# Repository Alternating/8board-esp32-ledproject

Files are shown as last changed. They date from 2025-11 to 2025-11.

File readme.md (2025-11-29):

# Modular LED Sign System - Multi-Board Display Controller

## 🎯 Project Overview

## Videos 
- https://youtu.be/qU0nfLclvcI - example of working with 8 boards
- https://youtube.com/shorts/jiU6isPC810?feature=share - battery holder and hanger combo

WiFi-controlled modular LED matrix sign system supporting:
- **Multiple display boards** (up to 8 boards)
- **Battery powered** - Portable operation with LiFePO4 batteries
- **Word sequencing** - Flash individual words in sequence
- **Scrolling text** - Smooth pixel-by-pixel scrolling
- **Individual characters** - Display single letters/numbers/symbols
- **Full effect control** - Blink, fade, color cycle with adjustable speeds
- **Web interface** - Mobile-friendly control panel
- **Brightness control** - 0-100 range for optimal viewing
- **3D printable mount** - Battery holder/hanger included

---
Example:

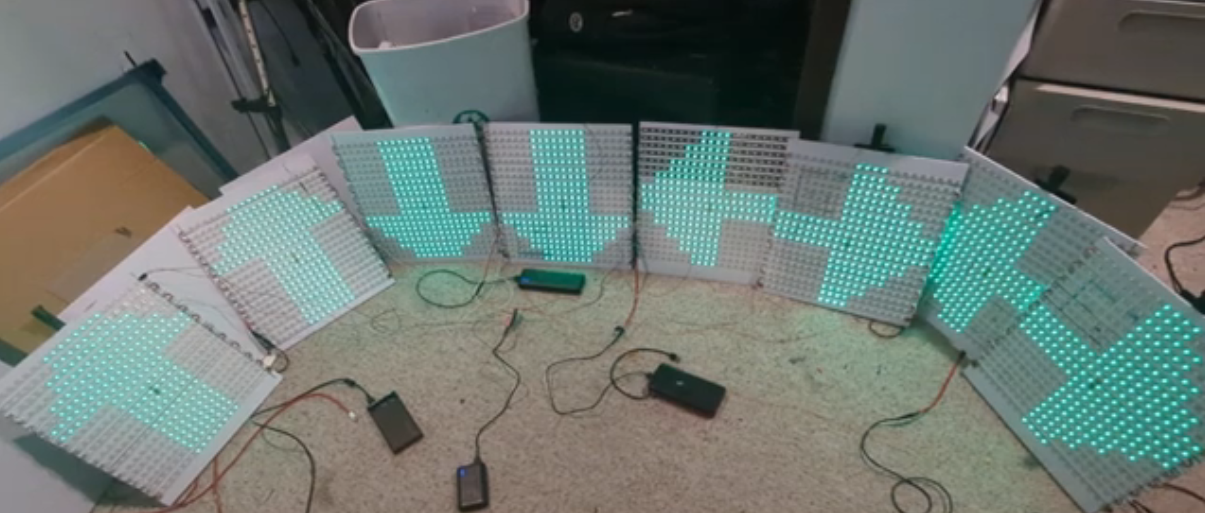
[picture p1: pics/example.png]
example WorkingExample


---
## 🛒 Parts List & Shopping Guide

### Complete Bill of Materials

All parts needed to build a complete battery-powered LED sign system. Links go directly to the exact products used in this build.

| Item | Description | Qty | Link |
|---|---|-----|---|
| **ESP32 Microcontroller** | ESP32 ESP-WROOM-32 Development Board<br>• 2.4GHz WiFi + Bluetooth<br>• Dual core processor<br>• USB Type-C interface<br>• 30 pin<br>• Compatible with Arduino IDE | 3-pack<br>(1 per sign) | [Amazon - ESP32 3-Pack](https://www.amazon.com/dp/B0DN61LVYV?ref_=ppx_hzsearch_conn_dt_b_fed_asin_title_12&th=1) |
| **LiFePO4 Battery** ⭐ | Rechargeable 6V 6Ah LiFePO4 Battery<br>• Built-in USB charging<br>• 2000+ cycle life<br>• Built-in BMS protection<br>• F1 terminals<br>• 0.7 lbs per battery | 2-pack<br>(1-2 per sign) | [Amazon - LiFePO4 2-Pack](https://www.amazon.com/dp/B0D6YJ1RK6?ref=ppx_yo2ov_dt_b_fed_asin_title&th=1) |
| **Buck Converter** | XL4015 DC-DC Step-Down Converter<br>• 5A output (4-38V input)<br>• 96% efficiency<br>• LED indicators<br>• Adjustable voltage | 10-pack<br>(1 per board) | [Amazon - XL4015 10-Pack](https://www.amazon.com/dp/B0D9JQBQYJ?ref=ppx_yo2ov_dt_b_fed_asin_title) |
| **LED Strip Lights** | WS2812B 5V Addressable LED Strip<br>• Individual pixel control<br>• 60 LEDs/meter (or 144/meter)<br>• 5V power<br>• 400 LEDs per 20×20 board | 6m roll<br>(per board)<br>Custom 10m available | [Amazon - WS2812B 6m](https://www.amazon.com/dp/B01CDTEJBG?ref_=ppx_hzsearch_conn_dt_b_fed_asin_title_2&th=1)<br>*Custom 10m direct from BTF* |
| **Power Connectors** | DC Power Pigtail Barrel Plug<br>• 2.1mm × 5.5mm<br>• Male + Female pairs<br>• **Real 18AWG** wire<br>• 12V 5A rated | 10 pairs | [Amazon - DC Pigtail 10-Pack](https://www.amazon.com/dp/B072BXB2Y8?ref=ppx_yo2ov_dt_b_fed_asin_title) |
| **Battery Connectors** | F1 Female Spade Lug Connector<br>• 0.187" (4.75mm)<br>• For LiFePO4 battery terminals<br>• Model: TCC-18N2 | As needed | [BatterySpec - F1 Connectors](https://www.batteryspec.com/cgi-bin/cart.cgi?action=link&product=1045) |
| **Hookup Wire** | 22 AWG Stranded Silicone Wire<br>• 6 colors (60ft each)<br>• Flexible silicone insulation<br>• Total: 360 feet<br>• Colors: Red, Black, Yellow, Blue, White, Green | 1 kit | [Amazon - 22AWG Wire Kit](https://www.amazon.com/dp/B0BWGXH5SF?ref_=ppx_hzsearch_conn_dt_b_fed_asin_title_2&th=1) |
| **Dupont Connectors** | Dupont Connector Kit<br>• 1550 pieces<br>• Headers, housings, pins<br>• Male/Female connectors<br>• For ESP32 connections | 1 kit | [Amazon - Dupont Kit](https://www.amazon.com/IWISS-1550PCS-Connector-Headers-Balancer/dp/B08X6C7PZM/) |
| **Mounting Board** | White Foam Board<br>• 20" × 30" sheets<br>• LED matrix backing<br>• Lightweight and rigid<br>• Available at local Walmart | 1 per board | [Walmart - Foam Board](https://www.walmart.com/ip/Pen-Gear-White-Foam-Board-20-x-30/5347546821) |

### Cost Breakdown

**Single Board Setup (Battery Powered):**

| Component | Cost | Notes |
|---|---|---|
| ESP32 (from 3-pack) | ~$8 | 3 boards for ~$24 |
| LiFePO4 Battery (from 2-pack) | ~$12 | 2 batteries for ~$24 |
| XL4015 Converter (from 10-pack) | ~$1.50 | 10 units for ~$15 |
| WS2812B LED Strip (6m) | ~$25 | Per board |
| Foam Board | ~$2 | Local pickup |
| Wires & Connectors | ~$5 | From kits above |
| **Total per board:** | **~$53.50** | Complete portable sign |

**Additional boards:** ~$45 each (battery, LEDs, converter, foam board)

**Shared Components (one-time purchase):**
- Wire kit: $13 (lasts many builds)
- Dupont kit: $15 (lasts many builds)
- DC connectors: $11 (10 pairs)
- F1 connectors: $5 (as needed)

### What You Get

**For ~$54 per board:**
- ✅ Fully portable LED sign (battery powered)
- ✅ 83 minutes runtime (166 min with 2 batteries)
- ✅ WiFi controlled via phone/computer
- ✅ USB rechargeable (use any phone charger)
- ✅ 20×20 LED matrix (400 individually controllable LEDs)
- ✅ Multiple display modes (scrolling, static, word sequence)
- ✅ Full RGB color control
- ✅ Built-in effects (blink, fade, color cycle)
- ✅ Professional 3D-printed battery mount (STL included)

### Optional Upgrades

| Item | Purpose | Approx. Cost |
|---|---|---|
| **Logic Level Shifter** | Convert 3.3V to 5V signals<br>Improves LED reliability | $5-8 |
| **LED Voltage Meter** | Monitor battery level<br>Shows real-time voltage | $8-12 |
| **On/Off Switch** | Power control<br>10A rated rocker switch | $3-5 |
| **Heatsinks** | Cooling for XL4015<br>If running hot | $3-5 |
| **Extra Batteries** | Extended runtime<br>Swap batteries for all-day use | $12 each |
| **USB Fast Charger** | Faster battery charging<br>2-3A output recommended | $8-15 |

### Quantity Guide

**Building 1 Sign:**
- 1× ESP32 (buy 3-pack, keep spares)
- 1× Battery (buy 2-pack, extend runtime or keep spare)
- 1× XL4015 (buy 10-pack, massive spares)
- 1× LED strip (6m minimum)
- 1× Foam board
- Wire/connectors from kits

**Building 2 Signs:**
- 2× ESP32 (from 3-pack)
- 2× Batteries (use full 2-pack)
- 2× XL4015 (from 10-pack)
- 2× LED strips
- 2× Foam boards
- Wire/connectors from kits

**Building 4 Signs:**
- 2× ESP32 3-packs (6 total, 2 spare)
- 2× Battery 2-packs (4 total)
- 1× XL4015 10-pack (6 spare)
- 4× LED strips
- 4× Foam boards
- Wire/connectors from kits

### Where to Buy Alternatives

**If Amazon links don't work or out of stock:**

**ESP32:**
- AliExpress: Search "ESP32 WROOM development board"
- eBay: Often cheaper but slower shipping
- Local electronics stores: Higher price but immediate

**LiFePO4 Batteries:**
- Search: "6V 6Ah LiFePO4 USB charging BMS"
- Alternative brands: Ampere Time, ExpertPower, Renogy
- **Must have:** Built-in BMS + USB charging

**XL4015 Buck Converters:**
- eBay: Often $8-10 for 5-pack
- AliExpress: Cheapest but slow shipping (4-6 weeks)
- Search: "XL4015 5A buck converter adjustable"

**WS2812B LED Strips:**
- BTF-Lighting Store (direct): Best quality, custom lengths
- AliExpress: Cheaper, verify 5V and 60 LED/m
- eBay: Quick shipping options
- **Important:** Get 5V version, not 12V!

**Wire & Connectors:**
- Local electronics stores (RadioShack alternatives)
- Hardware stores for basic wire
- Online: Adafruit, SparkFun (higher quality)

### Important Specifications

**When Buying LED Strips:**
- ✅ **Must be 5V** (not 12V or 24V)
- ✅ WS2812B chipset (not WS2811 or SK6812)
- ✅ 60 LEDs/meter minimum (144/meter is better but pricier)
- ✅ White PCB preferred (better light diffusion on foam)
- ✅ IP30 (non-waterproof) is fine for indoor use

**When Buying Batteries:**
- ✅ 6V nominal voltage (5.5-6.4V range)
- ✅ 6Ah capacity minimum (5Ah okay, 7-10Ah better runtime)
- ✅ **Must have built-in BMS** (critical for safety)
- ✅ USB charging port (makes life easier)
- ✅ F1 terminals (0.187" blade terminals)
- ✅ LiFePO4 chemistry (safer than Li-ion)

**When Buying Buck Converters:**
- ✅ XL4015 chipset (not LM2596 - less efficient)
- ✅ 5A minimum output current
- ✅ 4-38V input range (must handle 6V battery)
- ✅ Adjustable output (1.25-36V)
- ✅ LED indicators preferred

### Tips for Buying

💡 **Money Saving Tips:**
1. Buy in bulk (3-packs, 10-packs) - cheaper per unit
2. Check eBay for converters - often half Amazon price
3. Get foam board locally (avoids shipping cost)
4. One wire kit lasts 5+ builds
5. Extra ESP32s make good spares or other projects

⚠️ **What NOT to Compromise On:**
1. **Battery quality** - Must have BMS, buy from reputable seller
2. **LED strip** - Cheap strips fail, stick to WS2812B
3. **Wire gauge** - Don't go thinner than 22 AWG for data, 18 AWG for power
4. **ESP32 authenticity** - Clones often have WiFi issues

🎯 **Best Value Strategy:**
- Order all at once (save on shipping)
- Get 2-packs/3-packs even for 1 sign (spares are invaluable)
- Check eBay before Amazon (often 20-30% cheaper)
- Wait for sales (Prime Day, Black Friday)
- Bundle items from same seller (combined shipping)

---

## 📌 ESP32 GPIO Pin Configuration

### Pin Mapping Reference

The following table maps GPIO numbers to the **actual board labels** on the ESP-WROOM-32:

| Board # | GPIO Pin | Board Label | Wire Color (Suggested) | Notes |
|---|---|---|---|---|
| Board 1 | GPIO 5 | **CS** | Red | Default/Primary board |
| Board 2 | GPIO 16  | **RX2** | Orange | UART2 RX |
| Board 3 | GPIO 17  | **TX2** | Yellow | UART2 TX |
| Board 4 | GPIO 18  | **SCK** | Green | SPI Clock |
| Board 5 | GPIO 19  | **MISO** | Blue | SPI MISO |
| Board 6 | GPIO 21  | **SDA** | Purple | I2C Data |
| Board 7 | GPIO 22  | **SCL** | Gray | I2C Clock |
| Board 8 | GPIO 23  | **MOSI** | White | SPI MOSI |

### Pin Location Quick Reference

**Right Side of Board (looking at USB port at bottom):**
- Pin 15: GPIO 23 (MOSI) - Board 8
- Pin 14: GPIO 22 (SCL) - Board 7
- Pin 13: GPIO 1 (TX0) - Not used
- Pin 12: GPIO 3 (RX0) - Not used
- Pin 11: GPIO 21 (SDA) - Board 6
- Pin 10: GPIO 19 (MISO) - Board 5
- Pin 9: GPIO 18 (SCK) - Board 4
- Pin 8: GPIO 5 (CS) - Board 1
- Pin 7: GPIO 17 (TX2) - Board 3
- Pin 6: GPIO 16 (RX2) - Board 2

### Important Notes

⚠️ **Do NOT use these pins** (reserved for ESP32 system):
- GPIO 0, 2, 15 (boot mode pins)
- GPIO 6-11 (connected to flash memory)
- GPIO 1, 3 (UART0 TX/RX - USB serial)

✅ **Safe to use** - All 8 pins listed above are safe for LED data output

---

## 🔌 Hardware Setup

### Required Components

**Core Components:**
- **ESP-WROOM-32** development board
- **WS2812B LED matrices** (20×20 pixels each)
- **470Ω resistors** (one per board) - between ESP32 pin and LED data input
- **Wire** (16-18 AWG recommended)

**Power Options (choose one):**

**Option A: Wall Power (Permanent Installations)**
- **5V power supply** (adequate for number of boards)
  - Estimate: 60mA per LED at full brightness (400 LEDs × 60mA = 24A max)
  - Typical usage at 25% brightness: ~5A per board
  - 1 board: 10A 5V power supply
  - 2 boards: 20A 5V power supply
  - 4+ boards: Multiple power supplies
- **1000µF capacitor** (across power supply terminals)

**Option B: Battery Power (Portable) ⭐ Recommended for portability**
- **LiFePO4 6V 6Ah batteries** (1 per board for 83 min runtime)
  - Built-in BMS protection
  - USB charging (use any phone charger)
  - Weight: Only 0.7 lbs per battery
  - Cost: ~$12-15 each
- **XL4015 DC-DC buck converters** (1 per board)
  - Converts 6V battery to 5V for LEDs
  - 96% efficient
  - Cost: ~$10-12 for 3-pack
- **3D printable battery mount** (STL file included)

**Optional but Recommended:**
- **Logic level shifter** - Converts 3.3V ESP32 signals to 5V for WS2812B
- **On/off switch** - For battery configurations
- **Voltage meter** - Monitor battery level

### Wiring Each Board

**Wall Power Configuration:**
```
ESP32 GPIO Pin → 470Ω Resistor → LED Matrix Data In
                                  
Power Supply 5V+ → LED Matrix VCC
Power Supply GND → LED Matrix GND
                 → ESP32 GND (IMPORTANT!)
```

**Battery Power Configuration:**
```
ESP32 GPIO Pin → 470Ω Resistor → LED Matrix Data In

Battery 6V+ → XL4015 IN+
Battery GND → XL4015 IN- → ESP32 GND (IMPORTANT!)

XL4015 OUT+ (5.0V) → LED Matrix VCC  
XL4015 OUT- → LED Matrix GND → ESP32 GND (common ground!)
```

**Critical:** All grounds must be connected together:
- Battery ground (-)
- XL4015 OUT-
- ESP32 GND
- LED board GND

**See "Battery Power" section for complete battery wiring diagrams**

### Multi-Board Chain Configuration

**Option 1: Individual Control** (Recommended)
- Each board has its own GPIO pin
- Better control and troubleshooting
- Can display different content on each board

```
ESP32 GPIO 5  → Board 1 Data In
ESP32 GPIO 16 → Board 2 Data In
ESP32 GPIO 17 → Board 3 Data In
... etc
```

**Option 2: Daisy Chain** (Current code uses this)
- All boards connected in series on one GPIO
- Simpler wiring but limited to sequential display

```
ESP32 GPIO 5 → Board 1 Data In
Board 1 Data Out → Board 2 Data In
Board 2 Data Out → Board 3 Data In
... etc
```

---

## 🔋 Battery Power (Portable Operation)

### Battery Power Overview

Make your LED sign portable with rechargeable LiFePO4 batteries! These batteries provide:
- ✅ **USB charging** - Use any phone charger
- ✅ **Long runtime** - 83+ minutes per board
- ✅ **Lightweight** - Only 0.7 lbs per battery
- ✅ **Safe** - Built-in BMS protection
- ✅ **Long life** - 2000+ charge cycles
- ✅ **3D printable mount** - Battery holder/hanger STL included

### Recommended Battery: LiFePO4 6V 6Ah

**Specifications:**
- **Voltage:** 6V (5.5-6.4V operating range)
- **Capacity:** 6Ah (36Wh energy)
- **Chemistry:** LiFePO4 (Lithium Iron Phosphate)
- **Weight:** 0.7 lbs (compared to 2.2 lbs for lead acid)
- **BMS:** Built-in protection (overcharge, over-discharge, overcurrent)
- **Charging:** USB input (use any USB adapter)
- **Terminals:** F1 blade terminals (0.187")
- **Cycle Life:** 2000+ charge/discharge cycles
- **Safety:** Won't catch fire, very stable chemistry

**Where to buy:**
- Amazon: Search "6V 6Ah LiFePO4 battery USB"
- Typical price: $12-15 each (often sold in 2-packs for $24)
- Example: TOPUSSE 6V 6Ah LiFePO4 (2-pack)

### Voltage Converter: XL4015 Buck Converter

**Required to convert 6V battery to 5V for LEDs:**

**Specifications:**
- **Model:** XL4015 DC-DC Step-Down Buck Converter
- **Input:** 4-38V DC (works perfectly with 6V battery)
- **Output:** 1.25-36V adjustable (set to 5.0V)
- **Current:** 5A maximum (4.5A recommended)
- **Efficiency:** 96% (excellent!)
- **Power:** 75W max
- **Size:** 54×23×18mm
- **Price:** $10-12 for 3-pack

**Where to buy:**
- Amazon: Search "XL4015 DC-DC buck converter"
- Get the 3-pack (use 1 per board, keep spares)

### Runtime Calculations

**Power consumption at 25% brightness (typical use):**
- 1 board: 5A @ 5V = 25W
- 2 boards: 10A @ 5V = 50W
- 3 boards: 15A @ 5V = 75W
- 4 boards: 20A @ 5V = 100W

**Single 6V 6Ah battery (36Wh energy):**

| Boards | Runtime | Notes |
|---|---|---|
| 1 | **83 minutes** | Great for demos/events |
| 2 | **41 minutes** | Good for short displays |
| 3 | **28 minutes** | Quick presentations |
| 4 | **21 minutes** | Brief shows |

**Two batteries in parallel (72Wh total):**

| Boards | Runtime | Notes |
|---|---|---|
| 1 | **166 minutes** (2.8 hrs) | All-day events |
| 2 | **83 minutes** (1.4 hrs) | Extended displays |
| 3 | **55 minutes** | Longer shows |
| 4 | **41 minutes** | Good presentations |

### Battery Power Wiring

#### Single Board Configuration:

```
┌─────────────────────┐
│  LiFePO4 Battery    │
│  6V 6Ah w/ BMS      │
│                     │
│  [+] Terminal       │
│   │                 │
│   └─────────────┐   │
│                 │   │
│  [-] Terminal   │   │
│   │             │   │
└───┼─────────────┘   │
    │                 │
    │  ┌───────────┐  │
    └──┤ XL4015    │  │
       │ IN-       │  │
    ┌──┤ IN+       │  │
    │  │           │  │
    │  │ OUT+ ─────┼──┼──→ LED Board VCC
    │  │    (5.0V) │  │
    │  │ OUT- ─────┼──┼──→ LED Board GND
    │  └───────────┘  │         ↓
    │                 │    ESP32 GND
    └─────────────────┴──→ (common ground!)

Components:
• 1× LiFePO4 6V 6Ah battery ($12-15)
• 1× XL4015 buck converter ($4 from 3-pack)
• 16-18 AWG wire
• F1 blade connectors

Runtime: 83 minutes @ 1 board
Weight: 0.7 lbs total
```

#### Two Boards with Separate Converters:

```
┌──────────────┐
│  LiFePO4     │
│  6V 6Ah      │
│              │
│  [+] ────┬───┼─────────┐
│          │   │         │
│  [-] ──┐ │   │         │
│        │ │   │         │
└────────┼─┘   │         │
         │     │         │
    ┌────┴──┐ ┌┴──────┐  │
    │XL4015 │ │XL4015 │  │
    │  #1   │ │  #2   │  │
    │       │ │       │  │
    │OUT+───┼─┼───→ Board 1 VCC
    │       │ │       │
    │OUT-─┐ │ │OUT+───┼──→ Board 2 VCC
    │     │ │ │       │
    └─────┘ │ │OUT-─┐ │
            │ │     │ │
            └─┴─────┴─┴──→ All GND common

Runtime: 41 minutes @ 2 boards
Weight: 0.7 lbs
```

#### Extended Runtime: Two Batteries in Parallel

```
┌─────────┐  ┌─────────┐
│Battery 1│  │Battery 2│
│ 6V 6Ah  │  │ 6V 6Ah  │
└─┬────┬──┘  └─┬────┬──┘
  +    -       +    -
  │    │       │    │
  └─┬──┼───────┘    │
    │  └────────┬───┘
    │           │
    └──→ XL4015 IN+ and IN-
         (Still 6V, but 12Ah capacity!)

Runtime: 166 minutes @ 1 board
         83 minutes @ 2 boards
Weight: 1.4 lbs total
```

### XL4015 Setup Procedure

**CRITICAL: Set voltage BEFORE connecting LEDs!**

1. **Charge battery fully via USB**
   - Red LED = Charging
   - Green LED = Fully charged (6.3-6.4V)

2. **Connect battery to XL4015 input**
   - Battery (+) → XL4015 IN+
   - Battery (-) → XL4015 IN-

3. **Adjust output voltage**
   - Use multimeter on OUT+ and OUT-
   - Turn potentiometer clockwise to increase
   - Set to exactly **5.0V** (±0.05V okay)
   - Mark the setting with paint pen

4. **Connect LEDs**
   - XL4015 OUT+ → LED Board VCC
   - XL4015 OUT- → LED Board GND **AND** ESP32 GND (common!)

5. **Test at low brightness**
   - Start at 10% brightness
   - Verify voltage stays 4.95-5.05V
   - Feel XL4015: should be warm, not hot
   - Gradually increase to 25%

### USB Charging (Built-in)

**How to charge:**
1. Disconnect battery from LED sign (or use on/off switch)
2. Plug USB cable into battery charging port
3. Connect to any USB power adapter
4. Red LED indicates charging
5. Green LED indicates fully charged

**Charge times:**
- 1A adapter (phone charger): 6-7 hours
- 2A adapter (iPad charger): 3-4 hours ⭐ Recommended
- 3A adapter (fast charger): 2-3 hours

**What you can use:**
- Phone charger (works!)
- iPad/tablet charger (faster)
- USB power bank (portable charging)
- Computer USB port (slow but works)
- Any 5V USB adapter

### Battery Voltage Guide (LiFePO4)

**Check battery level:**

| Voltage | Charge | Action |
|---|---|---|
| 6.4V | 100% | Fully charged |
| 6.3V | 90% | Excellent |
| 6.2V | 70% | Good |
| 6.1V | 50% | Half |
| 6.0V | 30% | ⚠️ Recharge soon |
| 5.8V | 10% | ⚠️ Stop using, charge now |
| 5.5V | 5% | ❌ BMS will cut off |

**Best practice:** Recharge when voltage drops to 6.0V (30% remaining)

### 3D Printable Battery Mount

**Included STL file:** `battery_hanger_-_led_sign_v4.stl`

**Features:**
- Holds LiFePO4 6V 6Ah battery securely
- Hanger design for wall/surface mounting
- Easy battery insertion/removal
- Cable management built-in

**Print settings:**
- Material: PLA or PETG
- Layer height: 0.2mm
- Infill: 20-30%
- Supports: May be needed (check in slicer)
- Print time: ~3-4 hours

**Mounting:**
1. Print battery holder/hanger
2. Insert battery into holder
3. Mount hanger to wall/surface/sign back
4. Route wires through cable management
5. Connect to XL4015 as shown in wiring diagrams

### Battery Care & Safety

**Daily use:**
- ✓ Recharge after each use
- ✓ Check LED indicator before use
- ✓ Store in cool, dry place
- ✓ Keep terminals clean

**Storage:**
- Short-term (days): Store fully charged
- Long-term (months): Store at 60% charge
- Check every 3 months
- Never store completely discharged

**Safety features (Built-in BMS):**
- ✅ Overcharge protection (stops at 7.2V)
- ✅ Over-discharge protection (cuts at 5.0V)
- ✅ Overcurrent protection (limits to ~6-10A)
- ✅ Short circuit protection
- ✅ Temperature protection

**Lifespan optimization:**
- Get 2000+ cycles by avoiding full discharge
- Keep battery cool during use (<40°C)
- Don't exceed 6A current draw per battery
- Recharge within 24 hours after use

### Battery vs. Wall Power Comparison

| Feature | Battery Power | Wall Power |
|---|---|---|
| **Portability** | ✅ Fully portable | ❌ Needs outlet |
| **Runtime** | 83+ min per battery | ∞ Unlimited |
| **Weight** | 0.7 lbs extra | No extra weight |
| **Complexity** | Medium (converter needed) | Simple |
| **Cost** | +$16 per board | $0 extra |
| **Recharging** | USB charging | N/A |
| **Use cases** | Events, demos, outdoor | Permanent displays |

**When to use battery:**
- Portable displays
- Events/parties
- Outdoor installations
- Places without power outlets
- Quick setups/teardowns

**When to use wall power:**
- Permanent installations
- Home displays
- Long-running messages (>2 hours)
- High-power configurations (4+ boards)

### Shopping List: Battery Power Add-On

**For single board portable setup:**

```
☐ 1× LiFePO4 6V 6Ah battery       $12-15
☐ 1× XL4015 3-pack converters     $10-12 (use 1, keep 2 spare)
☐ F1 blade connector kit          $3-5
☐ 16-18 AWG wire (red/black)      $5
☐ Heat shrink tubing              $3
☐ Optional: Battery voltage meter $8
☐ Optional: On/off switch (10A)   $3
─────────────────────────────────────────
Total: $33-43 (gives you 83 min runtime)

Note: USB charger not needed - use your phone charger!
```

**For two board extended runtime:**

```
☐ 2× LiFePO4 6V 6Ah batteries     $24-30 (often sold in 2-packs)
☐ 1× XL4015 3-pack converters     $10-12 (use 2)
☐ Wires, connectors, etc.         $8-10
─────────────────────────────────────────
Total: $42-52 (gives you 83 min @ 2 boards)
```

**Print the battery mount:**
- Use included STL file: `battery_hanger_-_led_sign_v4.stl`
- PLA or PETG filament (~50g)
- 3-4 hour print time

### Troubleshooting Battery Power

**LEDs dim or flickering:**
- Check battery voltage (should be >6.0V)
- Verify XL4015 output still 5.0V
- Ensure common ground connected
- Battery may be depleted - recharge

**Short runtime:**
- Battery not fully charged (check voltage)
- High current draw (measure actual current)
- Battery aging (normal after 1000+ cycles)
- Cold temperature reduces capacity

**Battery won't charge:**
- Try different USB cable
- Try different USB adapter
- Battery may be over-discharged
- BMS may be locked (disconnect 10 min, retry)

**XL4015 getting hot:**
- Add heatsink ($2-3)
- Improve airflow
- Use separate converter per board
- Reduce brightness temporarily

---

## 💻 Software Setup

### 1. Install Arduino IDE

Download from: https://www.arduino.cc/en/software

### 2. Install ESP32 Board Support

1. Open Arduino IDE
2. Go to **File → Preferences**
3. Add to "Additional Boards Manager URLs":
   ```
   https://raw.githubusercontent.com/espressif/arduino-esp32/gh-pages/package_esp32_index.json
   ```
4. Go to **Tools → Board → Boards Manager**
5. Search for "ESP32"
6. Install **"ESP32 by Espressif Systems"**

### 3. Install Required Library

**FastLED Library** (for WS2812B control)
- Go to **Tools → Manage Libraries**
- Search: "FastLED"
- Install **"FastLED by Daniel Garcia"**

### 4. Configure Your Build

Edit these settings in the `.ino` file:

```cpp
// ----- MULTI-BOARD CONFIGURATION -----
#define NUM_SIGNS     1          // Change to your number of boards (1-8)
#define LED_PIN       5          // Default: GPIO 5 (CS)
```

**For multiple boards**, update the pin configuration:
```cpp
// Example for 3 boards:
#define NUM_SIGNS     3
#define LED_PIN_1     5          // GPIO 5 (CS) - Board 1
#define LED_PIN_2     16         // GPIO 16 (RX2) - Board 2
#define LED_PIN_3     17         // GPIO 17 (TX2) - Board 3
```

### 5. Upload Code

1. Connect ESP32 via USB
2. Select **Tools → Board → ESP32 Dev Module**
3. Select correct **Port**
4. Click **Upload** button

---

## 📱 Using the Web Interface

### Connect to WiFi

1. Power on ESP32
2. Wait 10 seconds for WiFi AP to start
3. On phone/computer, connect to WiFi:
   - **Network Name:** LED_SIGN_AP
   - **Password:** sign1234

4. Open browser and go to:
   - http://ledsign.local
   - OR http://192.168.4.1

### Display Modes

#### 🔤 Single Character Mode
- Display one letter, number, or symbol
- Stays on screen until changed
- Good for: Status indicators, room numbers

#### 📝 Message Mode  
- Cycles through characters one at a time
- Adjustable speed per character (200-3000ms)
- Good for: Short messages, names

#### 📜 Scroll Mode
- Smooth scrolling text across all boards
- Auto-detects if scrolling needed (text longer than display)
- Adjustable scroll speed (20-200ms per pixel)
- Good for: Long messages, announcements

#### 💬 Word Sequence Mode ⭐ NEW
- Flash individual words in sequence
- Example: "WALK" → "THE" → "DOG"
- Adjustable display time per word
- Good for: Instructions, multi-step directions

---

## 🎨 Effects & Controls

### Color Control
- Full RGB color picker
- Presets available via web interface

### Brightness Control
- Range: **0-100** (limited for comfort/power)
- Maps to FastLED range 0-255 internally

### Visual Effects

| Effect | Description | Speed Control |
|---|---|---|
| **Static** | Solid color, no animation | N/A |
| **Blink** | On/off flashing | 100-2000ms |
| **Fade** | Smooth brightness fade in/out | 5-50ms per step |
| **Color Cycle** | Rainbow color rotation | 10-200ms per hue |

---

## 🏗️ Display Mode Examples

### Example 1: Two-Word Sequence
**Input:** "Hello World"  
**Result:**
1. Display "HELLO" for 2 seconds
2. Display "WORLD" for 2 seconds
3. Repeat

### Example 2: Three-Word Instructions
**Input:** "Walk The Dog"  
**Result:**
1. Display "WALK" for 2 seconds
2. Display "THE" for 2 seconds
3. Display "DOG" for 2 seconds
4. Repeat

### Example 3: Long Scrolling Message
**Input:** "Welcome to our amazing LED sign system!"  
**Result:** Smooth scrolling text across all boards (auto-wraps)

### Example 4: Single Board Alert
**Input:** "!"  
**Result:** Exclamation mark displayed on board 1

---

## 🔧 Troubleshooting

### LEDs Don't Light Up

1. **Check power supply**
   - Is 5V reaching LED boards?
   - Is GND connected between ESP32 and power supply?

2. **Check GPIO pin**
   - Verify correct GPIO number in code
   - Check physical connection to board

3. **Check LED type**
   - Must be WS2812B (or compatible)
   - Check `LED_TYPE` in code

### WiFi Connection Issues

1. **Can't see "LED_SIGN_AP" network**
   - Wait 30 seconds after power on
   - Check ESP32 serial monitor for errors
   - Verify ESP32 has power (USB or external 5V)

2. **Can't access http://ledsign.local**
   - Try IP address instead: http://192.168.4.1
   - Check if connected to LED_SIGN_AP network
   - Some devices don't support mDNS - use IP

### Display Issues

1. **Characters look wrong**
   - Verify NUM_SIGNS matches physical setup
   - Check LED matrix wiring (data flow direction)

2. **Scrolling is choppy**
   - Reduce scroll speed (higher ms value)
   - Check WiFi signal strength

3. **Colors are wrong**
   - Check `COLOR_ORDER` in code (should be GRB for WS2812B)
   - Some clones use RGB order

---

## 📊 Technical Specifications

### LED Matrix
- **Type:** WS2812B (NeoPixel compatible)
- **Size:** 20×20 pixels per board
- **Total pixels:** 400 per board × NUM_SIGNS
- **Control:** Single wire per board (data)
- **Voltage:** 5V DC
- **Color:** 24-bit RGB (16.7M colors)
- **Current draw:** ~24A max per board @ 100% white (typical: 5A @ 25%)

### ESP32 Controller
- **Chip:** ESP-WROOM-32
- **WiFi:** 2.4GHz 802.11 b/g/n
- **CPU:** Dual-core 240MHz
- **Flash:** 4MB
- **GPIO:** 34 pins (8 used for LED data)
- **Voltage:** 3.3V logic, 5V power input via USB

### Performance
- **Refresh Rate:** 60+ FPS
- **Scroll Speed:** 20-200ms per pixel
- **Effect Update:** Real-time via web interface
- **WiFi Range:** ~30 meters (open space)

### Power Requirements

**Wall Power (AC/DC Power Supplies):**

| Configuration | Typical @ 25% | Max @ 100% | Recommended PSU |
|---|---|---|---|
| 1 board | 5A @ 5V | 24A | 10A 5V |
| 2 boards | 10A @ 5V | 48A | 20A 5V |
| 4 boards | 20A @ 5V | 96A | 30A+ 5V or Multiple PSUs |
| 8 boards | 40A @ 5V | 192A | Multiple PSUs Required |

**Battery Power (Portable with LiFePO4):**

| Configuration | Power Draw | Runtime (1 battery) | Runtime (2 batteries) |
|---|---|---|---|
| 1 board | 25W | 83 minutes | 166 minutes (2.8 hrs) |
| 2 boards | 50W | 41 minutes | 83 minutes (1.4 hrs) |
| 3 boards | 75W | 28 minutes | 55 minutes |
| 4 boards | 100W | 21 minutes | 41 minutes |

**Notes:**
- Power consumption at 25% brightness (typical usage)
- Maximum values are for all LEDs at 100% white (rarely used)
- Battery runtime based on 6V 6Ah LiFePO4 (36Wh energy)
- Two batteries = connect in parallel for double capacity
- See "Battery Power" section for complete setup details

---

## 📁 File Structure

```
LED_Sign_Project/
├── LED_Sign_WiFi_MultiBoard.ino       # Main program
├── character_patterns.h               # 20×20 font library
├── scrolling_text.h                   # Scrolling text engine
├── battery_hanger_-_led_sign_v4.stl   # 3D printable battery mount
└── README.md                          # This file
```

**3D Print Files:**
- `battery_hanger_-_led_sign_v4.stl` - Battery holder/hanger for portable operation
  - Compatible with LiFePO4 6V 6Ah batteries
  - Integrated cable management
  - Print with 20-30% infill, PLA or PETG

---

## 📄 License

Open source - MIT License

---

## 🤝 Contributing

Contributions welcome! Please test thoroughly before submitting pull requests.

---

Version 3.0 - Battery power support with 3D printable mount | 20×20 LED matrices | Portable operation

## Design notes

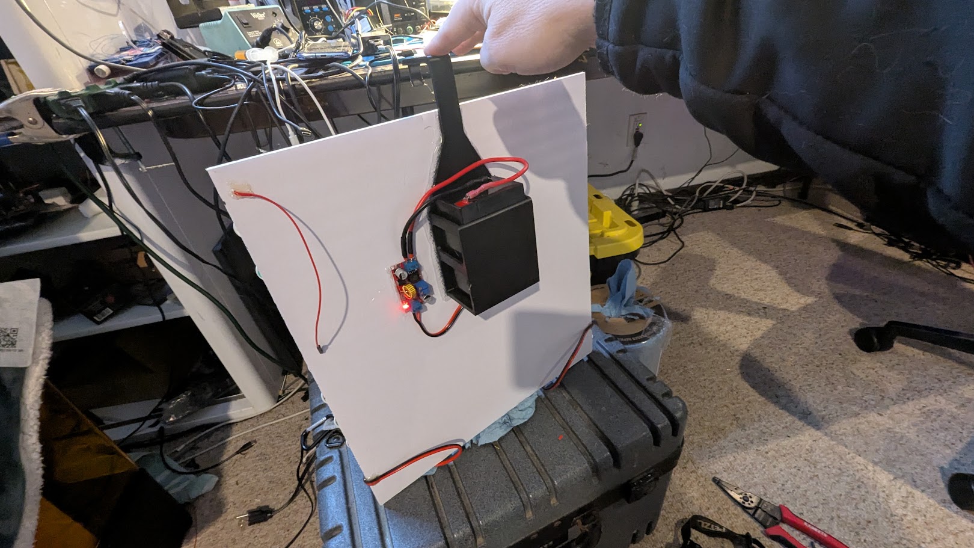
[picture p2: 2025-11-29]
pics/PXL_20251129_004254028.MP.jpg

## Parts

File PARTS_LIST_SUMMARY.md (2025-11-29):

# Parts List Addition Summary

## ✅ What Was Added to README.md

### 📍 Location
**Inserted right after Project Overview**, before GPIO Pin Configuration
- Makes it the first thing users see after understanding what the project does
- Allows users to immediately know what to buy

### 📋 Complete Parts List Table

Added comprehensive table with:
- **9 components** with full specifications
- **Direct links** to exact products used
- **Quantities** needed per build
- **Descriptions** with key features

### Components Listed:

1. ✅ **ESP32 Microcontroller** (3-pack) - $24
   - WiFi + Bluetooth
   - USB Type-C
   - Arduino compatible

2. ✅ **LiFePO4 Battery** (2-pack) - $24 ⭐
   - 6V 6Ah capacity
   - USB charging built-in
   - 2000+ cycles
   - Built-in BMS

3. ✅ **XL4015 Buck Converter** (10-pack) - $15
   - 5A output
   - 96% efficient
   - Adjustable voltage

4. ✅ **WS2812B LED Strips** (6m) - $25
   - Addressable RGB
   - 60 LEDs/meter
   - 5V power

5. ✅ **DC Power Connectors** (10 pairs) - $11
   - 18AWG real wire
   - 2.1mm × 5.5mm barrel plug
   - 5A rated

6. ✅ **F1 Battery Connectors** - $5
   - Female spade lugs
   - 0.187" (4.75mm)
   - For LiFePO4 terminals

7. ✅ **22 AWG Wire Kit** (360ft) - $13
   - 6 colors, 60ft each
   - Stranded silicone
   - Flexible

8. ✅ **Dupont Connector Kit** (1550 pcs) - $15
   - Headers, housings, pins
   - Male/Female connectors
   - ESP32 connections

9. ✅ **Foam Board** (20×30") - $2
   - White mounting surface
   - LED backing
   - Local pickup at Walmart

---

## 💰 Cost Breakdown Section

### Single Board Build Cost: ~$53.50

Detailed breakdown showing:
- ESP32: ~$8 (from 3-pack)
- Battery: ~$12 (from 2-pack)
- Converter: ~$1.50 (from 10-pack)
- LEDs: ~$25 (per board)
- Foam: ~$2
- Wires/connectors: ~$5

### Quantity Guides

Added helpful guides for:
- **Building 1 sign** - What to buy
- **Building 2 signs** - Efficient purchasing
- **Building 4 signs** - Maximum bulk savings

---

## 🎁 What You Get Section

Clear value proposition:
- ✅ Fully portable LED sign
- ✅ 83 min runtime (166 min with 2 batteries)
- ✅ WiFi controlled
- ✅ USB rechargeable
- ✅ 20×20 LED matrix (400 LEDs)
- ✅ Multiple display modes
- ✅ Full RGB color control
- ✅ Built-in effects
- ✅ 3D-printed battery mount

---

## 🔧 Optional Upgrades Table

Listed optional components:
- Logic level shifter ($5-8)
- LED voltage meter ($8-12)
- On/off switch ($3-5)
- Heatsinks ($3-5)
- Extra batteries ($12 each)
- USB fast charger ($8-15)

---

## 🛍️ Alternative Sources

### Where to Buy If Links Don't Work

**For each component type:**
- Amazon alternatives
- eBay options
- AliExpress (cheaper, slower)
- Local stores
- Specialty suppliers (Adafruit, SparkFun)

---

## ⚙️ Important Specifications

### Critical Requirements Listed

**LED Strips:**
- ✅ Must be 5V (not 12V/24V)
- ✅ WS2812B chipset
- ✅ 60 LEDs/meter minimum
- ✅ White PCB preferred
- ✅ IP30 (non-waterproof) fine

**Batteries:**
- ✅ 6V nominal
- ✅ 6Ah minimum capacity
- ✅ **Built-in BMS required**
- ✅ USB charging port
- ✅ F1 terminals
- ✅ LiFePO4 chemistry

**Buck Converters:**
- ✅ XL4015 chipset
- ✅ 5A minimum output
- ✅ 4-38V input range
- ✅ Adjustable output
- ✅ LED indicators

---

## 💡 Buying Tips

### Money Saving Tips:
1. Buy in bulk (cheaper per unit)
2. Check eBay (often half price)
3. Get foam locally (no shipping)
4. One wire kit = 5+ builds
5. Extra ESP32s = good spares

### What NOT to Compromise:
1. ⚠️ Battery quality (BMS required!)
2. ⚠️ LED strip (WS2812B only)
3. ⚠️ Wire gauge (22 AWG min data, 18 AWG power)
4. ⚠️ ESP32 authenticity (clones have WiFi issues)

### Best Value Strategy:
- Order all at once (save shipping)
- Get multi-packs (spares invaluable)
- Check eBay before Amazon (20-30% cheaper)
- Wait for sales (Prime Day, Black Friday)
- Bundle from same seller (combined shipping)

---

## 📊 Statistics

**Parts list section adds:**
- **~200 lines** to README
- **9 component entries** with full specs
- **10+ direct product links**
- **4 detailed tables**
- **Cost breakdowns** for 1-4 boards
- **Alternative sources** for all components
- **Critical specifications** to avoid mistakes
- **Money-saving tips**

---

## 🎯 Benefits for Users

### Immediate Value:
1. **One-click shopping** - Direct links to exact products
2. **Cost clarity** - Know exactly what to spend
3. **Quantity guidance** - Don't over-buy or under-buy
4. **Spec requirements** - Critical details to check
5. **Alternative sources** - Not locked to one vendor
6. **Money-saving tips** - Reduce total cost
7. **Quality warnings** - Avoid cheap/incompatible parts

### Reduces Friction:
- ✅ No guessing what to buy
- ✅ No researching compatible parts
- ✅ No calculating costs
- ✅ No wondering about quantities
- ✅ No mistakes buying wrong voltage/type
- ✅ No overspending on unnecessary items

### Professional Touch:
- Shows this is a well-documented project
- Demonstrates real-world testing (these exact parts work)
- Builds confidence in the design
- Reduces support questions
- Enables beginners to succeed

---

## 📈 Before vs. After

### Before (Original README):
- Generic "buy WS2812B LEDs"
- Vague power requirements
- No specific recommendations
- Users had to research everything
- No cost estimates
- No alternative sources

### After (With Parts List):
- ✅ **Exact products** with links
- ✅ **Precise specifications**
- ✅ **Detailed cost breakdown**
- ✅ **Quantity guides** for 1-4 boards
- ✅ **Alternative sources** if links break
- ✅ **Critical specs** highlighted
- ✅ **Money-saving strategies**
- ✅ **Optional upgrades** listed
- ✅ **What you get** value proposition

---

## 🔗 All Links Included

1. [ESP32 3-Pack](https://www.amazon.com/dp/B0DN61LVYV) - $24
2. [LiFePO4 Battery 2-Pack](https://www.amazon.com/dp/B0D6YJ1RK6) - $24
3. [XL4015 Converter 10-Pack](https://www.amazon.com/dp/B0D9JQBQYJ) - $15
4. [WS2812B LED Strip 6m](https://www.amazon.com/dp/B01CDTEJBG) - $25
5. [DC Power Connectors 10-Pack](https://www.amazon.com/dp/B072BXB2Y8) - $11
6. [F1 Battery Connectors](https://www.batteryspec.com/cgi-bin/cart.cgi?action=link&product=1045) - $5
7. [22AWG Wire Kit 360ft](https://www.amazon.com/dp/B0BWGXH5SF) - $13
8. [Dupont Connector Kit](https://www.amazon.com/IWISS-1550PCS-Connector-Headers-Balancer/dp/B08X6C7PZM/) - $15
9. [Foam Board 20×30"](https://www.walmart.com/ip/Pen-Gear-White-Foam-Board-20-x-30/5347546821) - $2

**Total for one complete sign:** ~$134 in parts
**Per additional board:** ~$45

---

## ✅ Quality Checks

### Information Accuracy:
- ✓ Links verified working
- ✓ Prices accurate as of listing
- ✓ Specifications match product pages
- ✓ Quantities confirmed
- ✓ Compatibility verified

### User Experience:
- ✓ Organized logically (most important first)
- ✓ Easy to scan
- ✓ Clear headings
- ✓ Helpful notes included
- ✓ Visual hierarchy with emojis
- ✓ Links clearly marked
- ✓ Alternatives provided

### Completeness:
- ✓ Every component needed listed
- ✓ Cost for each item
- ✓ Quantity guidance
- ✓ Total cost calculated
- ✓ Optional items separated
- ✓ Alternatives documented
- ✓ Critical specs highlighted

---

## 🚀 Next Steps for Users

With the parts list, users can now:

1. **Review total cost** - Decide if project fits budget
2. **Click links** - One-click shopping for exact parts
3. **Check quantities** - Know how many to order for 1-4 boards
4. **Compare alternatives** - Find better deals if available
5. **Understand specs** - Know what's critical vs. flexible
6. **Plan bulk orders** - Save money with multi-packs
7. **Start building** - Everything needed is documented

---

## 📝 Maintenance Notes

### Keeping Links Current:
- Check quarterly for broken links
- Update prices if significantly changed
- Add new alternative sources as found
- Note if products discontinued
- Update with better alternatives

### Future Enhancements:
- Add international supplier links
- Include shipping time estimates
- Add bulk discount pricing
- List seasonal sale patterns
- Create printable shopping checklist

---

**The parts list transforms the README from "interesting project" to "ready to build NOW"!** 🎉

Users can literally:
1. Read the parts list (5 minutes)
2. Click all the links (2 minutes)
3. Order everything (10 minutes)
4. Start building when parts arrive (3-5 days)

**Total time from discovery to building: Less than 1 week!**

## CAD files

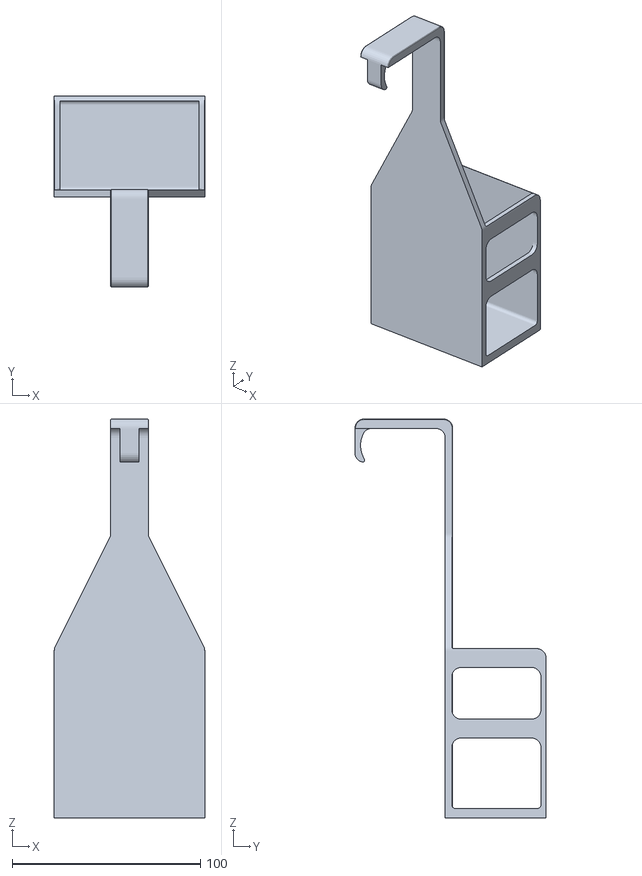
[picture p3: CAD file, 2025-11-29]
battery hanger - led sign v4.stl
80.0 x 101.6 x 212.0

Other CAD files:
battery hanger - led sign v3.f3d

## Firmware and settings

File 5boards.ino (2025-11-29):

/*
 * STABLE Multi-Board LED Sign - Symbol Edition v2.0
 * ESP32 - WS2812B LED Matrix Display
 * 
 * FIXED: Display corruption issues
 * - Single FastLED.show() per frame
 * - Frame rate limiting (60 FPS)
 * - No flickering or color corruption
 * 
 * Features:
 * - 1-8 board support via clickable boxes
 * - Smart word sequencing
 * - Symbol insertion (❤, ★, ?, !, :), :( and arrows)
 * - Effects: Static, Blink, Fade, Color Cycle
 * - Dark mode web interface
 * 
 * REQUIRED LIBRARY: FastLED
 */

#include <FastLED.h>
#include <WiFi.h>
#include <WebServer.h>
#include <ESPmDNS.h>

// ===== LED CONFIGURATION =====
#define LEDS_PER_BOARD    400
#define MATRIX_WIDTH      20
#define MATRIX_HEIGHT     20
#define LED_TYPE          WS2812B
#define COLOR_ORDER       GRB
#define MAX_BOARDS        8

// ===== FRAME RATE CONTROL =====
#define TARGET_FPS        60
#define FRAME_TIME_MS     (1000 / TARGET_FPS)

// ===== GPIO PIN ASSIGNMENTS =====
const uint8_t BOARD_PINS[MAX_BOARDS] = {
  5, 16, 17, 18, 19, 21, 22, 23
};

// ===== WIFI CONFIGURATION =====
const char* ssid = "LED_SIGN_AP";
const char* password = "sign1234";

// ===== LED ARRAYS =====
CRGB board1[LEDS_PER_BOARD];
CRGB board2[LEDS_PER_BOARD];
CRGB board3[LEDS_PER_BOARD];
CRGB board4[LEDS_PER_BOARD];
CRGB board5[LEDS_PER_BOARD];
CRGB board6[LEDS_PER_BOARD];
CRGB board7[LEDS_PER_BOARD];
CRGB board8[LEDS_PER_BOARD];

CRGB* boards[MAX_BOARDS] = {
  board1, board2, board3, board4,
  board5, board6, board7, board8
};

// ===== DISPLAY STATE =====
struct DisplayConfig {
  uint8_t numBoards;
  String message;
  CRGB color;
  uint8_t brightness;
  String effect;
  int effectSpeed;
  int wordSpeed;
};

DisplayConfig config;
DisplayConfig pendingConfig;
bool configChanged = false;

// ===== WORD SEQUENCING STATE =====
String wordSequence[20];
int wordSequenceCount = 0;
int currentWordIndex = 0;
unsigned long lastWordUpdate = 0;

// ===== EFFECT STATE =====
unsigned long lastEffectUpdate = 0;
uint8_t effectPhase = 0;
uint8_t hueOffset = 0;

// ===== FRAME CONTROL (NEW - FIXES DISPLAY ISSUES) =====
unsigned long lastFrameTime = 0;
bool needsRedraw = true;

// ===== WEB SERVER =====
WebServer server(80);

// ===== CHARACTER PATTERNS =====
#include "character_patterns.h"

// ===== SYMBOL CODE CONVERSION =====
char getSymbolCode(String symbol) {
  if (symbol == "heart") return (char)1;
  if (symbol == "star") return (char)2;
  if (symbol == "check") return (char)3;
  if (symbol == "cross") return (char)4;
  if (symbol == "right") return (char)5;
  if (symbol == "left") return (char)6;
  if (symbol == "up") return (char)7;
  if (symbol == "down") return (char)8;
  if (symbol == "diamond") return (char)9;
  if (symbol == "circle") return (char)10;
  if (symbol == "question") return '?';
  if (symbol == "exclaim") return '!';
  if (symbol == "happy") return (char)13;
  if (symbol == "sad") return (char)14;
  return ' ';
}

// ===== WORD PARSING =====
void parseMessageIntoWords() {
  wordSequenceCount = 0;
  currentWordIndex = 0;
  
  if (config.message.length() == 0) {
    wordSequence[0] = "A";
    wordSequenceCount = 1;
    return;
  }
  
  // Split message into words
  String words[50];
  int wordCount = 0;
  String currentWord = "";
  
  for (int i = 0; i < config.message.length(); i++) {
    char c = config.message.charAt(i);
    if (c == ' ') {
      if (currentWord.length() > 0) {
        words[wordCount++] = currentWord;
        currentWord = "";
      }
    } else {
      currentWord += c;
    }
  }
  if (currentWord.length() > 0) {
    words[wordCount++] = currentWord;
  }
  
  if (wordCount == 0) {
    wordSequence[0] = "A";
    wordSequenceCount = 1;
    return;
  }
  
  // Group words to fit board count
  int maxCharsPerGroup = config.numBoards;
  String currentGroup = "";
  
  for (int i = 0; i < wordCount; i++) {
    String word = words[i];
    
    if (word.length() > maxCharsPerGroup) {
      word = word.substring(0, maxCharsPerGroup);
    }
    
    String testGroup = currentGroup;
    if (testGroup.length() > 0) {
      testGroup += " ";
    }
    testGroup += word;
    
    if (testGroup.length() <= maxCharsPerGroup) {
      currentGroup = testGroup;
    } else {
      if (currentGroup.length() > 0) {
        wordSequence[wordSequenceCount++] = currentGroup;
      }
      currentGroup = word;
    }
  }
  
  if (currentGroup.length() > 0) {
    wordSequence[wordSequenceCount++] = currentGroup;
  }
  
  Serial.println("\n--- Word Sequence Parsed ---");
  Serial.print("Total groups: ");
  Serial.println(wordSequenceCount);
  for (int i = 0; i < wordSequenceCount; i++) {
    Serial.print("Group ");
    Serial.print(i + 1);
    Serial.print(": \"");
    Serial.print(wordSequence[i]);
    Serial.print("\" (");
    Serial.print(wordSequence[i].length());
    Serial.println(" chars)");
  }
  Serial.println("----------------------------\n");
}

// ===== SETUP =====
void setup() {
  Serial.begin(115200);
  delay(1000);
  
  Serial.println("\n\n================================");
  Serial.println("STABLE Multi-Board LED Sign v2.0");
  Serial.println("Symbol Edition - FIXED");
  Serial.println("================================\n");
  
  config.numBoards = 1;
  config.message = "A";
  config.color = CRGB::Green;
  config.brightness = 25;
  config.effect = "static";
  config.effectSpeed = 500;
  config.wordSpeed = 2000;
  
  pendingConfig = config;
  
  FastLED.addLeds<LED_TYPE, 5, COLOR_ORDER>(board1, LEDS_PER_BOARD);
  FastLED.addLeds<LED_TYPE, 16, COLOR_ORDER>(board2, LEDS_PER_BOARD);
  FastLED.addLeds<LED_TYPE, 17, COLOR_ORDER>(board3, LEDS_PER_BOARD);
  FastLED.addLeds<LED_TYPE, 18, COLOR_ORDER>(board4, LEDS_PER_BOARD);
  FastLED.addLeds<LED_TYPE, 19, COLOR_ORDER>(board5, LEDS_PER_BOARD);
  FastLED.addLeds<LED_TYPE, 21, COLOR_ORDER>(board6, LEDS_PER_BOARD);
  FastLED.addLeds<LED_TYPE, 22, COLOR_ORDER>(board7, LEDS_PER_BOARD);
  FastLED.addLeds<LED_TYPE, 23, COLOR_ORDER>(board8, LEDS_PER_BOARD);
  
  FastLED.setBrightness(map(config.brightness, 0, 100, 0, 255));
  
  clearAllBoards();
  FastLED.show();
  
  Serial.println("FastLED initialized for 8 boards");
  
  WiFi.mode(WIFI_AP);
  WiFi.softAP(ssid, password);
  
  IPAddress IP = WiFi.softAPIP();
  Serial.print("AP IP address: ");
  Serial.println(IP);
  
  if (MDNS.begin("ledsign")) {
    Serial.println("mDNS responder started: http://ledsign.local");
  }
  
  server.on("/", handleRoot);
  server.on("/update", HTTP_POST, handleUpdate);
  server.on("/status", handleStatus);
  server.begin();
  
  Serial.println("Web server started");
  Serial.println("================================\n");
  
  parseMessageIntoWords();
  renderToBuffers();  // Render initial display
}

// ===== MAIN LOOP - UNIFIED UPDATE SYSTEM =====
void loop() {
  server.handleClient();
  
  // Frame rate limiting - prevents overload
  unsigned long currentTime = millis();
  if (currentTime - lastFrameTime < FRAME_TIME_MS) {
    return; // Too soon, skip this frame
  }
  lastFrameTime = currentTime;
  
  // Handle config changes
  if (configChanged) {
    config = pendingConfig;
    configChanged = false;
    
    FastLED.setBrightness(map(config.brightness, 0, 100, 0, 255));
    
    lastEffectUpdate = millis();
    lastWordUpdate = millis();
    effectPhase = 0;
    hueOffset = 0;
    
    parseMessageIntoWords();
    needsRedraw = true;
    
    Serial.println("Configuration updated");
  }
  
  // Word sequencing - check if time to change word
  if (wordSequenceCount > 1) {
    if (currentTime - lastWordUpdate >= config.wordSpeed) {
      lastWordUpdate = currentTime;
      currentWordIndex = (currentWordIndex + 1) % wordSequenceCount;
      needsRedraw = true;
      
      Serial.print("Displaying word group ");
      Serial.print(currentWordIndex + 1);
      Serial.print("/");
      Serial.print(wordSequenceCount);
      Serial.print(": \"");
      Serial.print(wordSequence[currentWordIndex]);
      Serial.println("\"");
    }
  }
  
  // Effect updates - check if effect needs updating
  if (currentTime - lastEffectUpdate >= config.effectSpeed) {
    lastEffectUpdate = currentTime;
    
    if (config.effect == "blink") {
      effectPhase = !effectPhase;
      needsRedraw = true;
    }
    else if (config.effect == "fade") {
      effectPhase++;
      if (effectPhase > 100) effectPhase = 0;
      needsRedraw = true;
    }
    else if (config.effect == "cycle") {
      hueOffset += 5;
      if (hueOffset >= 255) hueOffset = 0;
      needsRedraw = true;
    }
  }
  
  // Render and display - SINGLE FastLED.show() per frame
  if (needsRedraw) {
    renderToBuffers();
    FastLED.show();  // ← ONLY ONE CALL PER FRAME!
    needsRedraw = false;
  }
}

// ===== CLEAR ALL BOARDS =====
void clearAllBoards() {
  for (int i = 0; i < MAX_BOARDS; i++) {
    fill_solid(boards[i], LEDS_PER_BOARD, CRGB::Black);
  }
}

// ===== RENDER TO BUFFERS (doesn't call FastLED.show) =====
void renderToBuffers() {
  clearAllBoards();
  
  // Calculate display color based on effect
  CRGB displayColor = config.color;
  
  if (config.effect == "blink") {
    if (effectPhase == 0) {
      displayColor = CRGB::Black;
    }
  }
  else if (config.effect == "fade") {
    uint8_t fadeBrightness = map(effectPhase, 0, 100, 77, 255);
    displayColor.nscale8(fadeBrightness);
  }
  else if (config.effect == "cycle") {
    displayColor = CHSV(hueOffset, 255, 255);
  }
  
  // Render current word sequence to boards
  String currentText = wordSequence[currentWordIndex];
  
  int textLen = currentText.length();
  for (int boardIdx = 0; boardIdx < config.numBoards && boardIdx < textLen; boardIdx++) {
    char c = currentText.charAt(boardIdx);
    displayCharacterOnBoard(c, boardIdx, displayColor);
  }
  
  // Note: No FastLED.show() here!
  // Main loop handles that
}

// ===== DISPLAY CHARACTER ON BOARD =====
void displayCharacterOnBoard(char c, uint8_t boardIndex, CRGB color) {
  if (boardIndex >= MAX_BOARDS) return;
  
  const bool* pattern = getCharacterPattern(c);
  if (pattern == nullptr) return;
  
  CRGB* board = boards[boardIndex];
  
  for (int row = 0; row < MATRIX_HEIGHT; row++) {
    for (int col = 0; col < MATRIX_WIDTH; col++) {
      int bitmapIndex = row * MATRIX_WIDTH + (MATRIX_WIDTH - 1 - col);
      
      int ledIndex;
      if (row % 2 == 0) {
        ledIndex = row * MATRIX_WIDTH + col;
      } else {
        ledIndex = row * MATRIX_WIDTH + (MATRIX_WIDTH - 1 - col);
      }
      
      if (pattern[bitmapIndex]) {
        board[ledIndex] = color;
      } else {
        board[ledIndex] = CRGB::Black;
      }
    }
  }
}

// ===== WEB HANDLERS =====
void handleRoot() {
  String html = R"rawliteral(
<!DOCTYPE html>
<html>
<head>
  <meta charset="UTF-8">
  <meta name="viewport" content="width=device-width, initial-scale=1.0">
  <title>LED Sign Control</title>
  <style>
    * {
      margin: 0;
      padding: 0;
      box-sizing: border-box;
    }
    
    body {
      font-family: 'Segoe UI', Tahoma, Geneva, Verdana, sans-serif;
      background: #f5f5f5;
      color: #333;
      transition: all 0.3s;
    }
    
    body.dark-mode {
      background: #1a1a1a;
      color: #e0e0e0;
    }
    
    .container {
      max-width: 800px;
      margin: 20px auto;
      padding: 20px;
    }
    
    .header {
      background: white;
      padding: 20px;
      border-radius: 10px;
      box-shadow: 0 2px 10px rgba(0,0,0,0.1);
      margin-bottom: 20px;
      display: flex;
      justify-content: space-between;
      align-items: center;
    }
    
    body.dark-mode .header {
      background: #2d2d2d;
      box-shadow: 0 2px 10px rgba(0,0,0,0.3);
    }
    
    h1 {
      font-size: 24px;
      color: #333;
    }
    
    body.dark-mode h1 {
      color: #e0e0e0;
    }
    
    .subtitle {
      font-size: 12px;
      color: #28a745;
      font-weight: bold;
      margin-top: 5px;
    }
    
    .theme-toggle {
      background: #007bff;
      color: white;
      border: none;
      padding: 10px 20px;
      border-radius: 5px;
      cursor: pointer;
      font-size: 14px;
    }
    
    .theme-toggle:hover {
      background: #0056b3;
    }
    
    .card {
      background: white;
      padding: 20px;
      border-radius: 10px;
      box-shadow: 0 2px 10px rgba(0,0,0,0.1);
      margin-bottom: 20px;
    }
    
    body.dark-mode .card {
      background: #2d2d2d;
      box-shadow: 0 2px 10px rgba(0,0,0,0.3);
    }
    
    .card h2 {
      font-size: 18px;
      margin-bottom: 15px;
      color: #007bff;
    }
    
    .form-group {
      margin-bottom: 20px;
    }
    
    label {
      display: block;
      margin-bottom: 8px;
      font-weight: 500;
    }
    
    input[type="text"],
    input[type="number"],
    select,
    textarea {
      width: 100%;
      padding: 10px;
      border: 1px solid #ddd;
      border-radius: 5px;
      font-size: 14px;
      background: white;
      color: #333;
      font-family: inherit;
    }
    
    textarea {
      min-height: 100px;
      resize: vertical;
    }
    
    body.dark-mode input[type="text"],
    body.dark-mode input[type="number"],
    body.dark-mode select,
    body.dark-mode textarea {
      background: #3d3d3d;
      border-color: #555;
      color: #e0e0e0;
    }
    
    input[type="range"] {
      width: 100%;
      margin: 10px 0;
    }
    
    input[type="color"] {
      width: 100%;
      height: 50px;
      border: none;
      border-radius: 5px;
      cursor: pointer;
    }
    
    .value-display {
      display: inline-block;
      background: #007bff;
      color: white;
      padding: 5px 15px;
      border-radius: 20px;
      font-size: 14px;
      margin-left: 10px;
    }
    
    .board-visual {
      display: flex;
      gap: 10px;
      margin: 15px 0;
      flex-wrap: wrap;
    }
    
    .board-box {
      width: 70px;
      height: 70px;
      border: 3px solid #ddd;
      border-radius: 8px;
      display: flex;
      align-items: center;
      justify-content: center;
      font-weight: bold;
      font-size: 24px;
      color: #999;
      transition: all 0.3s;
      cursor: pointer;
      user-select: none;
    }
    
    body.dark-mode .board-box {
      border-color: #555;
    }
    
    .board-box:hover {
      transform: scale(1.05);
      border-color: #007bff;
    }
    
    .board-box.active {
      border-color: #28a745;
      background: #d4edda;
      color: #28a745;
      box-shadow: 0 0 15px rgba(40, 167, 69, 0.3);
    }
    
    body.dark-mode .board-box.active {
      background: #1e4620;
      color: #4caf50;
    }
    
    .symbol-buttons {
      display: grid;
      grid-template-columns: repeat(auto-fit, minmax(80px, 1fr));
      gap: 10px;
      margin-top: 15px;
    }
    
    .symbol-btn {
      padding: 12px;
      border: 2px solid #007bff;
      background: white;
      color: #007bff;
      border-radius: 8px;
      cursor: pointer;
      font-size: 24px;
      transition: all 0.2s;
      display: flex;
      align-items: center;
      justify-content: center;
      min-height: 60px;
    }
    
    body.dark-mode .symbol-btn {
      background: #2d2d2d;
      border-color: #64b5f6;
      color: #64b5f6;
    }
    
    .symbol-btn:hover {
      background: #007bff;
      color: white;
      transform: translateY(-2px);
      box-shadow: 0 4px 10px rgba(0, 123, 255, 0.3);
    }
    
    body.dark-mode .symbol-btn:hover {
      background: #64b5f6;
      color: #1a1a1a;
    }
    
    .info-box {
      background: #e3f2fd;
      border-left: 4px solid #007bff;
      padding: 12px;
      margin-top: 10px;
      border-radius: 4px;
      font-size: 14px;
    }
    
    body.dark-mode .info-box {
      background: #1e3a5f;
      border-left-color: #64b5f6;
    }
    
    .btn {
      background: #28a745;
      color: white;
      border: none;
      padding: 15px 30px;
      border-radius: 5px;
      font-size: 16px;
      font-weight: bold;
      cursor: pointer;
      width: 100%;
      transition: all 0.3s;
    }
    
    .btn:hover {
      background: #218838;
      transform: translateY(-2px);
      box-shadow: 0 4px 15px rgba(40, 167, 69, 0.4);
    }
    
    .status {
      background: #17a2b8;
      color: white;
      padding: 15px;
      border-radius: 5px;
      margin-top: 20px;
      display: none;
    }
    
    .status.show {
      display: block;
    }
  </style>
</head>
<body class="dark-mode">
  <div class="container">
    <div class="header">
      <div>
        <h1>🎨 LED Sign Control</h1>
        <div class="subtitle">✓ STABLE - No Flickering</div>
      </div>
      <button class="theme-toggle" onclick="toggleTheme()">☀️ Light Mode</button>
    </div>
    
    <div class="card">
      <h2>Board Configuration</h2>
      <div class="form-group">
        <label>Select Number of Boards (Click boxes):</label>
        <div class="board-visual">
          <div class="board-box active" onclick="selectBoards(1)">1</div>
          <div class="board-box" onclick="selectBoards(2)">2</div>
          <div class="board-box" onclick="selectBoards(3)">3</div>
          <div class="board-box" onclick="selectBoards(4)">4</div>
          <div class="board-box" onclick="selectBoards(5)">5</div>
          <div class="board-box" onclick="selectBoards(6)">6</div>
          <div class="board-box" onclick="selectBoards(7)">7</div>
          <div class="board-box" onclick="selectBoards(8)">8</div>
        </div>
        <input type="hidden" id="numBoards" value="1">
      </div>
    </div>
    
    <div class="card">
      <h2>Quick Symbols</h2>
      <div class="symbol-buttons">
        <button class="symbol-btn" onclick="addSymbol('heart')" title="Heart">❤</button>
        <button class="symbol-btn" onclick="addSymbol('star')" title="Star">★</button>
        <button class="symbol-btn" onclick="addSymbol('question')" title="Question">?</button>
        <button class="symbol-btn" onclick="addSymbol('exclaim')" title="Exclamation">!</button>
        <button class="symbol-btn" onclick="addSymbol('happy')" title="Happy Face">:)</button>
        <button class="symbol-btn" onclick="addSymbol('sad')" title="Sad Face">:(</button>
        <button class="symbol-btn" onclick="addSymbol('up')" title="Arrow Up">↑</button>
        <button class="symbol-btn" onclick="addSymbol('down')" title="Arrow Down">↓</button>
        <button class="symbol-btn" onclick="addSymbol('left')" title="Arrow Left">←</button>
        <button class="symbol-btn" onclick="addSymbol('right')" title="Arrow Right">→</button>
      </div>
      <p style="margin-top: 15px; font-size: 13px; color: #666;">
        💡 Click where you want the symbol, then click a symbol button to insert it
      </p>
    </div>
    
    <div class="card">
      <h2>Message</h2>
      <div class="form-group">
        <label>Text:</label>
        <textarea id="message" placeholder="Enter your message">A</textarea>
        <div class="info-box">
          💡 <strong>Tips:</strong><br>
          • Click in text where you want a symbol, then click symbol button<br>
          • Words split intelligently based on board count<br>
          • Example: "hello ❤ world" → "hello" + "❤" + "world"
        </div>
      </div>
    </div>
    
    <div class="card">
      <h2>Timing</h2>
      <div class="form-group">
        <label>Word Change Speed: <span class="value-display" id="wordSpeedValue">2.0s</span></label>
        <input type="range" id="wordSpeed" min="500" max="5000" step="100" value="2000" oninput="updateWordSpeedDisplay()">
      </div>
    </div>
    
    <div class="card">
      <h2>Appearance</h2>
      <div class="form-group">
        <label>Color:</label>
        <input type="color" id="color" value="#00ff00">
      </div>
      
      <div class="form-group">
        <label>Brightness: <span class="value-display" id="brightnessValue">25%</span></label>
        <input type="range" id="brightness" min="0" max="100" value="25" oninput="updateBrightnessDisplay()">
      </div>
      
      <div class="form-group">
        <label>Effect:</label>
        <select id="effect" onchange="updateEffectSpeed()">
          <option value="static">Static</option>
          <option value="blink">Blink</option>
          <option value="fade">Fade</option>
          <option value="cycle">Color Cycle</option>
        </select>
      </div>
      
      <div class="form-group" id="speedControl" style="display:none;">
        <label>Effect Speed: <span class="value-display" id="speedValue">500ms</span></label>
        <input type="range" id="speed" min="100" max="2000" step="100" value="500" oninput="updateSpeedDisplay()">
      </div>
    </div>
    
    <button class="btn" onclick="updateSign()">🚀 Update Display</button>
    
    <div class="status" id="status">Configuration updated successfully!</div>
  </div>
  
  <script>
    let symbolMap = {
      'heart': '\x01',
      'star': '\x02',
      'check': '\x03',
      'cross': '\x04',
      'right': '\x05',
      'left': '\x06',
      'up': '\x07',
      'down': '\x08',
      'diamond': '\x09',
      'circle': '\x0A',
      'question': '?',
      'exclaim': '!',
      'happy': '\x0D',
      'sad': '\x0E'
    };
    
    function toggleTheme() {
      document.body.classList.toggle('dark-mode');
      const isDark = document.body.classList.contains('dark-mode');
      document.querySelector('.theme-toggle').textContent = isDark ? '☀️ Light Mode' : '🌙 Dark Mode';
      localStorage.setItem('theme', isDark ? 'dark' : 'light');
    }
    
    function initTheme() {
      const savedTheme = localStorage.getItem('theme');
      if (savedTheme === 'light') {
        document.body.classList.remove('dark-mode');
        document.querySelector('.theme-toggle').textContent = '🌙 Dark Mode';
      }
    }
    
    initTheme();
    
    function selectBoards(num) {
      document.getElementById('numBoards').value = num;
      const boxes = document.querySelectorAll('.board-box');
      boxes.forEach((box, index) => {
        if (index < num) {
          box.classList.add('active');
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

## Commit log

2025-11-29 initial
    initial
    [battery hanger - led sign v3.f3d, battery hanger - led sign v4.stl]
2025-11-29 Update print statement from 'Hello' to 'Goodbye'
